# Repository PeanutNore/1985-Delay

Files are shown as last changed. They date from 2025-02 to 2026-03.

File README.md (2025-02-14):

# 1985-Delay
A Digital Delay pedal for guitar built around the AVR128DA28 MCU
    
This program is distributed in the hope that it will be useful,
but WITHOUT ANY WARRANTY; without even the implied warranty of
MERCHANTABILITY or FITNESS FOR A PARTICULAR PURPOSE.

 * Copyright 2025 Samuel Brown. All Rights Reservered.
 * 
 * Licensed under Creative Commons CC-BY-NC-SA 4.0
 * https://creativecommons.org/licenses/by-nc-sa/4.0/
 * 
 * You are free to share and adapt this software for non-
 * commercial purposes provided that you give appropriate 
 * credit and attribution, and distribute your contributions 
 * under the same CC-BY-NC-SA license.
 * 
 * For commercial licensing contact sam.brown.rit08@gmail.com

The maximum delay time available depends on the sample rate used and the bit depth of delay samples.
Main branch (1985_Delay) provides 1.4 seconds of delay at 10kHz and 8 bits and is tested and working with minor issues.
Highres branch (1985_Delay_Highres) provides 700ms of delay at 10kHz and 12 bits and is untested.

Adjust the sample rate as desired to balance available delay time and audio quality.

To use this software you will need:
* Arduino IDE version 1.8.19 or greater
* DxCore library for AVR128DA28 support (https://github.com/SpenceKonde/DxCore)
* Any USB to UPDI programmer. I recommend the Adafruit UPDI Friend because it is easy to use and under $20
* An AVR128DA28 MCU and appropriate supporting circuitry. Refer to the KiCad schematic and board files included in this repository.

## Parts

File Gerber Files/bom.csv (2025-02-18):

Designator | Footprint | Quantity | Value | LCSC Part #
C11, C16 | 603 | 2 | 1n2
C12 | 603 | 1 | 100n
C13 | 603 | 1 | 1n
C14, C6, C9 | 603 | 3 | 10n
C3, C5 | 1210 | 2 | 1u
R10, R11, R12, R13, R14, R15, R16, R17, R19, R7 | 805 | 10 | 22k
R18, R6 | 805 | 2 | 9k1
R20, R21, R5, R8, R9 | 805 | 5 | 1M
R4 | 805 | 1 | 1k
U1 | SOT-89-3 | 1 | L78L05
U2, U3 | SOT-89-3 | 2 | L78L33

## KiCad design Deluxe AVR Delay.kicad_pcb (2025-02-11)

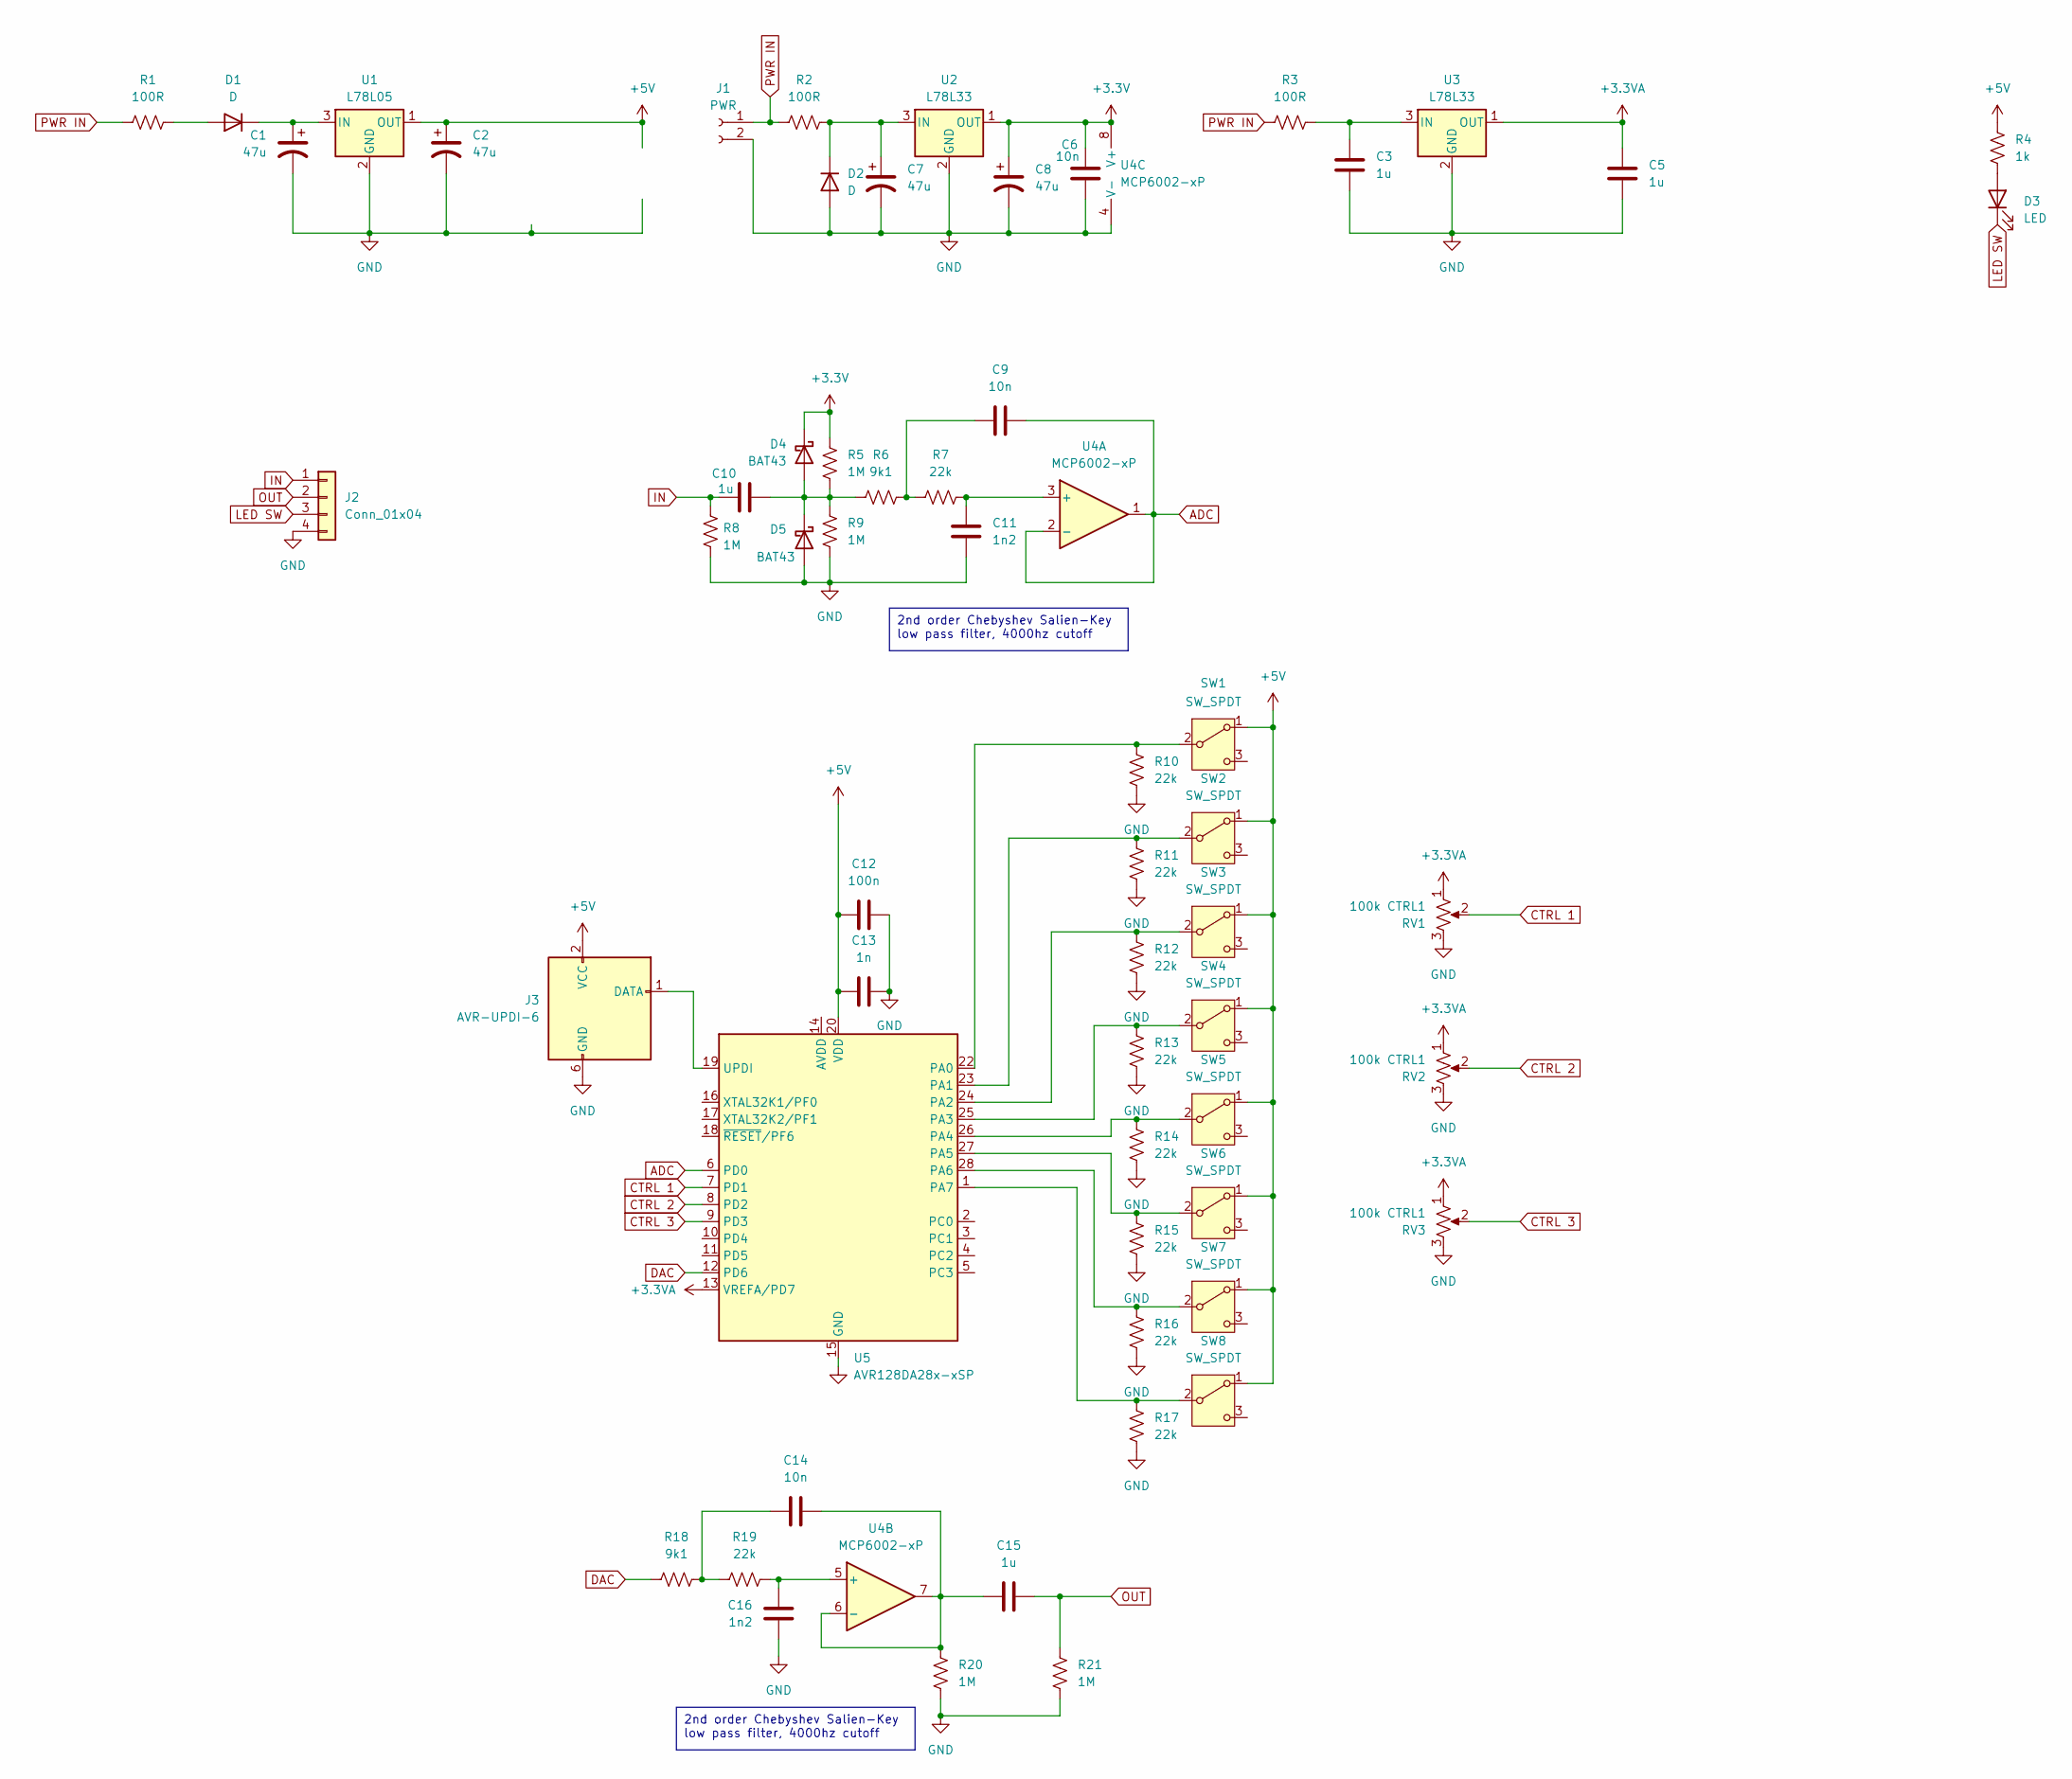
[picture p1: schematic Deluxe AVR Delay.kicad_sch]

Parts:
C1, C2, C7, C8: 47u; CP_Radial_D5.0mm_P2.50mm
C3, C5: 1u; C_1210_3225Metric
C6, C9, C14: 10n; C_0603_1608Metric
C10, C15: 1u; C_Rect_L7.0mm_W6.5mm_P5.00mm
C11, C16: 1n2; C_0603_1608Metric
C12: 100n; C_0603_1608Metric
C13: 1n; C_0603_1608Metric
D1, D2: D; D_DO-35_SOD27_P7.62mm_Horizontal
D3: LED; LED_D3.0mm
D4, D5: BAT43; D_DO-35_SOD27_P7.62mm_Horizontal
J1: PWR; PinHeader_1x02_P2.54mm_Vertical
J2: Conn_01x04; PinHeader_1x04_P2.54mm_Vertical
J3: AVR-UPDI-6; PinHeader_2x03_P2.54mm_Vertical
R1, R2, R3: 100R; R_Axial_DIN0207_L6.3mm_D2.5mm_P7.62mm_Horizontal
R4: 1k; R_0805_2012Metric
R5, R8, R9, R20, R21: 1M; R_0805_2012Metric
R6, R18: 9k1; R_0805_2012Metric
R7, R10, R11, R12, R13, R14, R15, R16, R17, R19: 22k; R_0805_2012Metric
RV1, RV2, RV3: 100k CTRL1; RV16AF-41
SW1, SW2, SW3, SW4, SW5, SW6, SW7, SW8: SW_SPDT; 2MS1T1B3M2QES
U1: L78L05; SOT-89-3
U2, U3: L78L33; SOT-89-3
U4: MCP6002-xP; DIP-8_W7.62mm_Socket
U5: AVR128DA28x-xSP; DIP-28_W7.62mm

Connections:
+3.3V: C6.1, C8.1, D4.1 (K), R5.1, U2.1 (OUT), U4.8 (V+)
+3.3VA: C5.2, RV1.1, RV2.1, RV3.1, U3.1 (OUT), U5.13 (VREFA/PD7)
+5V: C2.1, C12.1, C13.1, J3.2 (VCC), R4.1, SW1.1 (A), SW2.1 (A), SW3.1 (A), SW4.1 (A), SW5.1 (A), SW6.1 (A), SW7.1 (A), SW8.1 (A), U1.1 (OUT), U5.20 (VDD)
ADC: C9.2, U4.1, U4.2 (-), U5.6 (PD0)
CTRL 1: RV1.2, U5.7 (PD1)
CTRL 2: RV2.2, U5.8 (PD2)
CTRL 3: RV3.2, U5.9 (PD3)
DAC: R18.1, U5.12 (PD6)
GND: C1.2, C2.2, C3.1, C5.1, C6.2, C7.2, C8.2, C11.2, C12.2, C13.2, C16.2, D2.2 (A), D5.2 (A), J1.2, J2.4, J3.6 (GND), R8.2, R9.2, R10.1, R11.1, R12.1, R13.1, R14.1, R15.1, R16.1, R17.1, R20.2, R21.2, RV1.3, RV2.3, RV3.3, U1.2 (GND), U2.2 (GND), U3.2 (GND), U4.4 (V-), U5.15 (GND), U5.21 (GND)
IN: C10.1, J2.1, R8.1
LED SW: D3.1 (K), J2.3
unnamed: C9.1, R6.2, R7.1
unnamed: C14.1, R18.2, R19.1
unnamed: D1.2 (A), R1.2
unnamed: C1.1, D1.1 (K), U1.3 (IN)
unnamed: C7.1, D2.1 (K), R2.2, U2.3 (IN)
unnamed: D3.2 (A), R4.2
unnamed: C10.2, D4.2 (A), D5.1 (K), R5.2, R6.1, R9.1
unnamed: J3.1 (DATA), U5.19 (UPDI)
unnamed: R10.2, SW1.2 (B), U5.22 (PA0)
unnamed: R11.2, SW2.2 (B), U5.23 (PA1)
unnamed: R12.2, SW3.2 (B), U5.24 (PA2)
unnamed: R13.2, SW4.2 (B), U5.25 (PA3)
unnamed: R14.2, SW5.2 (B), U5.26 (PA4)
unnamed: R15.2, SW6.2 (B), U5.27 (PA5)
unnamed: R16.2, SW7.2 (B), U5.28 (PA6)
unnamed: R17.2, SW8.2 (B), U5.1 (PA7)
unnamed: C3.2, R3.2, U3.3 (IN)
unnamed: C11.1, R7.2, U4.3 (+)
unnamed: C16.1, R19.2, U4.5 (+)
unnamed: C14.2, C15.1, R20.1, U4.6 (-), U4.7
OUT: C15.2, J2.2, R21.1
PWR IN: J1.1, R1.1, R2.1, R3.1

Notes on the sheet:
2nd order Chebyshev Salien-Key low pass filter, 4000hz cutoff

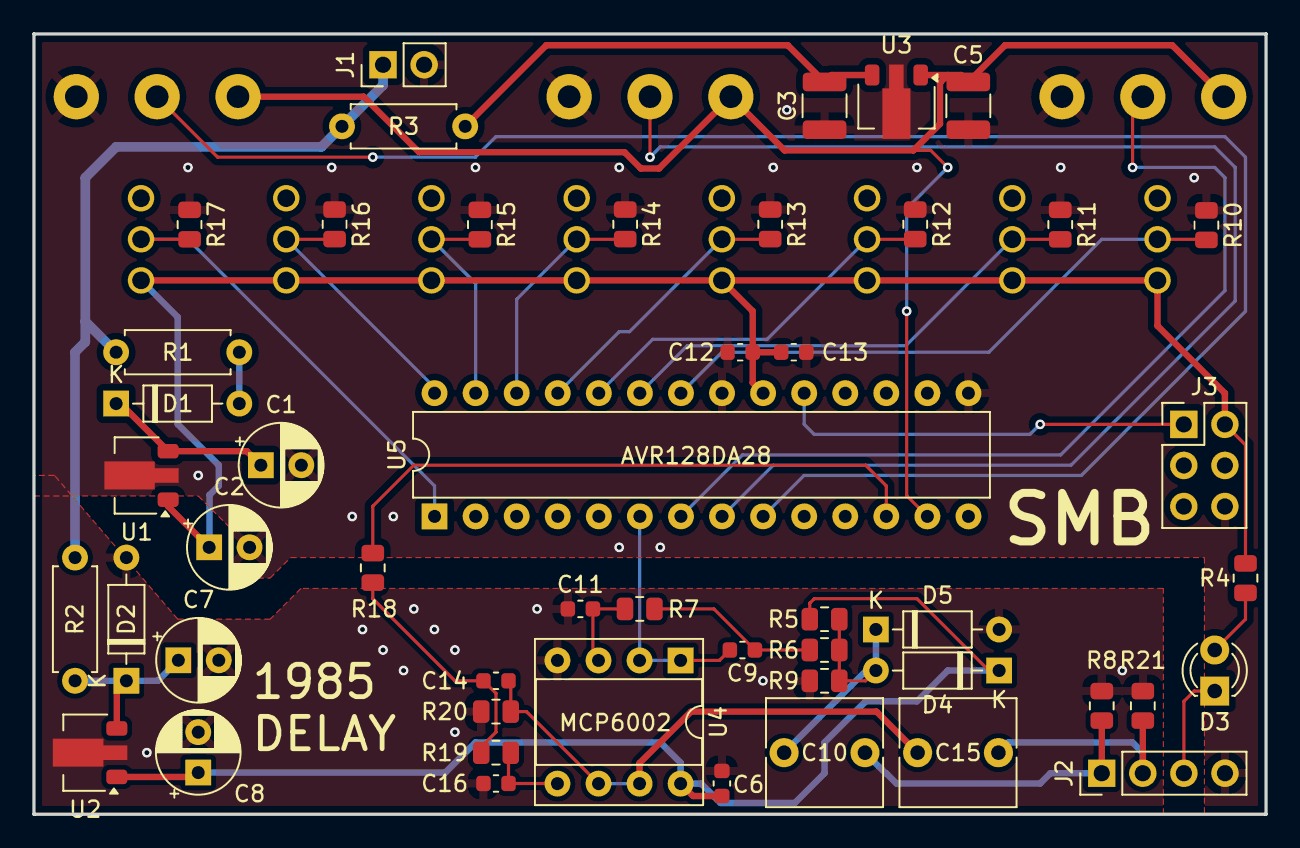
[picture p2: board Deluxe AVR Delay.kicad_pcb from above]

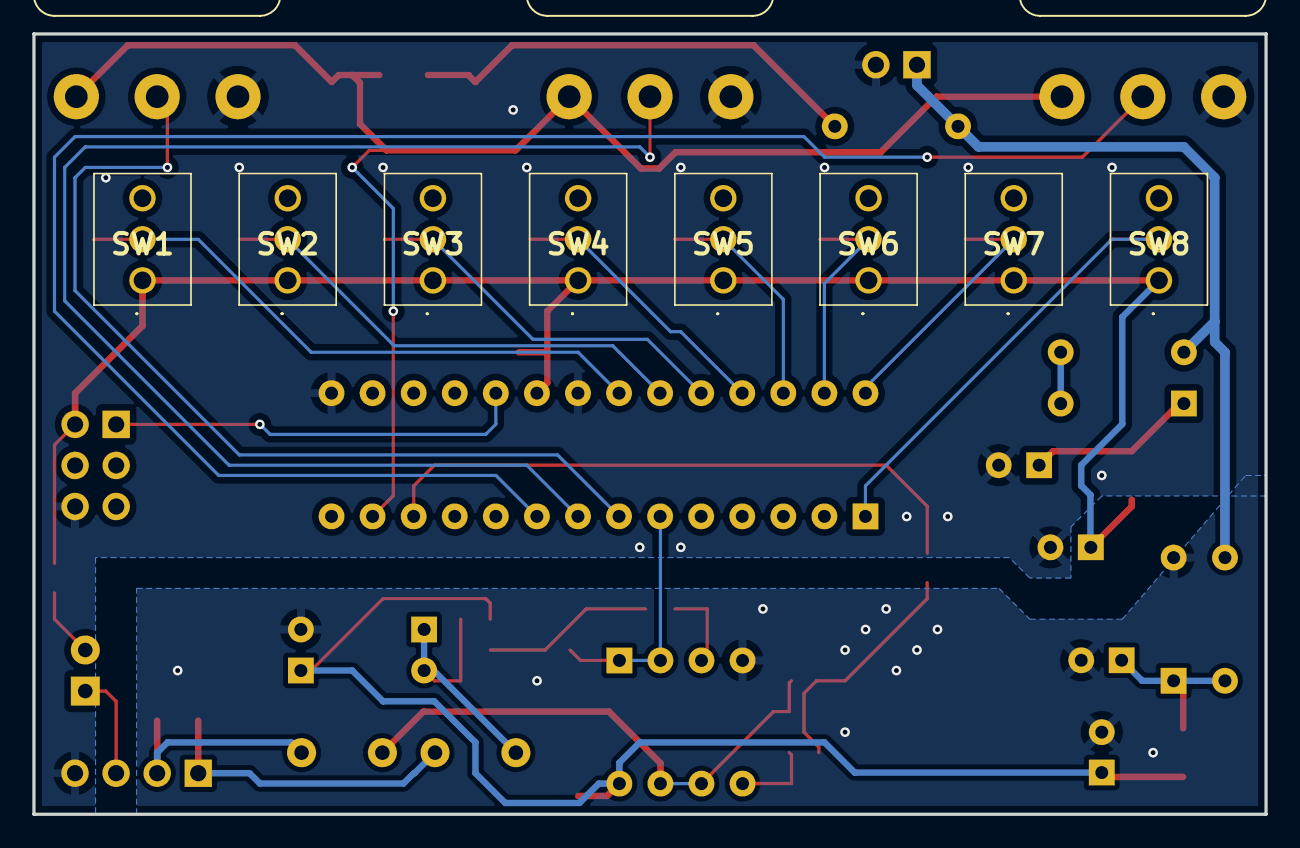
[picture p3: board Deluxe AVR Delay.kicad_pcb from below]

Board: 2 copper layers, 76.2 x 48.3 mm, 60 parts (11 on the bottom side), 33 nets.

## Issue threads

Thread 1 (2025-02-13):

Repeats louder than unity gain

PeanutNore, 2025-02-13:
at the center settings of the mix control, the repeats sound louder than unity gain as compared to the dry signal. this may be distortion caused by storing only the 8 most significant bits of the delayed sample.

possible fixes:

- store the full 10 bits of the delayed sample (cost: halves delay time, but there's a lot of delay time)
- cap delayed sample amplitude to 512 (9 bits)

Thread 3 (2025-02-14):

Temporal isolation of analogRead()s

PeanutNore, 2025-02-14:
To reduce jitter, isolate the analogRead()s from each other. Each one should be done immediately before that variable is first used within the ISR.

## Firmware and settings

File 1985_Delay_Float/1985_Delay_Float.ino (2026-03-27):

//Pin Assignments
uint8_t OutputPin = PIN_PD6;
uint8_t InputPin = PIN_PD0;
uint8_t TimePin = PIN_PD2;
uint8_t MixPin = PIN_PD1;
uint8_t FbkPin = PIN_PD3;
//Audio Samples
int16_t inSample;
int16_t delaySample;
float drySample;
float wetSample;
float storeSample;
float outSample;
int16_t intSample;
uint16_t dacSample;
int16_t delayArray[4096];

//Step Counters
uint16_t sampleStep = 0;
uint16_t delayStep = 0;

//Controls
uint16_t mixRaw = 0;
float mixFactor = 0.0;
uint16_t fbkRaw = 0;
float fbkFactor = 0.0;
uint16_t delaySet = 0;
uint16_t delayTimeNew = 0;
uint16_t delayTime = 0;

ISR(TCA0_OVF_vect) {
  //experiment here - clearing the interrupt flag first
  TCA0.SINGLE.INTFLAGS = TCA_SINGLE_OVF_bm;                 //clear the interrupt flags
  //get the input as a signed int
  inSample = analogRead(InputPin) - 2048;
  //get the signed int delayed sample
  delaySample = delayArray[delayStep];
  
  //convert the dry sample to a float between 1 and -1
  drySample = inSample / 2048.0;
  //convert the wet sample to a float between 1 and -1
  wetSample = delaySample / 2048.0;
  //prepare the sample to store in the array by starting with the feedback
  storeSample = wetSample;
  //attenuate the feedback
  storeSample *= fbkFactor;
  //add the dry sample
  storeSample += drySample;
  //convert to signed int
  delaySample = storeSample * 2048;
  //store the signed int sample in the delay
  delayArray[sampleStep] = delaySample;
  //attenuate the wet sample
  wetSample *= mixFactor;
  //combine the dry and wet samples together
  outSample = drySample + wetSample;
  //convert back to a signed int
  intSample = outSample * 2048;
  //constrain to the limits of the dac and make it unsigned
  if(intSample > 2047){intSample = 2047;}
  else if (intSample < -2048){intSample = -2048;}
  dacSample = intSample + 2048;
  dacSample = dacSample >> 2;
  //output to dac
  DAC0.DATAL = dacSample << 6;
  DAC0.DATAH = dacSample >> 2;
  //read the controls
  mixRaw = 4095 - (analogRead(MixPin) & 0b0000111111111100);
  mixFactor = mixRaw / 4095.0;
  fbkRaw = 4095 - (analogRead(FbkPin) & 0b0000111111111100);
  fbkFactor = fbkRaw / 4095.0;
  delayTimeNew = 4095 - (analogRead(TimePin) & 0b0000111111111100);
  if(delayTime < delayTimeNew){delayTime++;}
  else if (delayTime > delayTimeNew){delayTime--;}
  //increment the steps
  sampleStep++;
  sampleStep &= 0x0FFF;
  delayStep = sampleStep - delayTime;
  delayStep &= 0x0FFF;
  
}

void setup() {
  // put your setup code here, to run once:
for (int i = 0; i < 4096; i++){
  delayArray[i] = 0.0;
}
pinMode(OutputPin, OUTPUT);
pinMode(InputPin, INPUT);
pinMode(TimePin, INPUT);
pinMode(MixPin, INPUT);
pinMode(FbkPin, INPUT);
analogReference(EXTERNAL);
DACReference(EXTERNAL); //found to be missing when testing on final hardware- not an issue on the breadboard running everything at 5V
analogReadResolution(12);
analogSampleDuration(0);

mixRaw = analogRead(MixPin);
delayTime = 4095 - (analogRead(TimePin) & 0b0000111111111100);
mixFactor = mixRaw / 4095.0;

DAC0.DATAL = 0b00000000;
DAC0.DATAH = 0b10000000;
DAC0.CTRLA = 0b11000001;
takeOverTCA0();
TCA0.SINGLE.INTFLAGS = TCA_SINGLE_OVF_bm;
TCA0.SINGLE.INTCTRL  = 0b00000001; // overflow interrupt every PER cycles
TCA0.SINGLE.CTRLA    = TCA_SINGLE_CLKSEL_DIV1_gc; // Clock prescaler / 1 (24 MHz)    
TCA0.SINGLE.PER      = 1000;        // 300 * 8 = 2400 clocks, for a 10kHz sample rate, 200 * 8 = 1600 clocks 15kHz sample rate, 150 * 8 = 1200 clocks 20kHz sample rate, 125 * 8 = 1000 clocks 24kHz sample rate
TCA0.SINGLE.CTRLA   |= 1;          // Enables the timer                 
}

void loop() {
  // put your main code here, to run repeatedly:

}

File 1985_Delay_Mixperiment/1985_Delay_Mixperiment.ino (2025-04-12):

/* 1985 Delay
 * Digital Delay Pedal for Guitar
 * High resolution version with half delay time - reads and stores full 12 bit samples in delay array
 * Version 0.2 - tested and working on breadboard
 * 
 *
 * 
 * For AVR512DA28 microcontrollers using DxCore library
 * 
 * Copyright 2025 Samuel Brown. All Rights Reservered.
 * 
 * Licensed under Creative Commons CC-BY-NC-SA 4.0
 * https://creativecommons.org/licenses/by-nc-sa/4.0/
 * 
 * You are free to share and adapt this software for non-
 * commercial purposes provided that you give appropriate 
 * credit and attribution, and distribute your contributions 
 * under the same CC-BY-NC-SA license.
 * 
 * For commercial licensing contact sam.brown.rit08@gmail.com
 */

//Pin Assignments
uint8_t OutputPin = PIN_PD6;
uint8_t InputPin = PIN_PD0;
uint8_t TimePin = PIN_PD2;
uint8_t MixPin = PIN_PD1;
uint8_t FbkPin = PIN_PD3;
//Audio Samples
uint16_t sampleIn;
uint16_t sampleDelay;
uint16_t sampleFbk;
uint16_t sampleOut;
uint8_t sampleOutHigh;
uint8_t sampleOutLow;
int16_t mathIn;
int16_t mathDelay;
int16_t mathFbk;
int16_t mathOut;
uint16_t delayArray[8000];
//Step Counters
uint16_t sampleStep = 0;
uint16_t delayStep = 0;
//Controls
uint16_t delayTime = 0;
uint16_t mix = 8;
uint16_t fbk = 8;
//Lookup Tables
uint16_t mixOffsets[17] = {0, 1920, 1792, 1664, 1536, 1408, 1280, 1152, 1024, 896, 768, 640, 512, 384, 256, 128, 0};

ISR(TCA0_OVF_vect) {
  //experiment here - clearing the interrupt flag first
  TCA0.SINGLE.INTFLAGS = TCA_SINGLE_OVF_bm;                 //clear the interrupt flags
  //this concludes the experiment. don't forget about the commented line below.
  //read the audio input
  sampleIn = analogRead(InputPin);                          

  //read the delay time
  delayTime = analogRead(TimePin) >> 4;
  ADC0.MUXPOS = ((InputPin & 0x7F) << ADC_MUXPOS_gp);
  delayTime *= 32;
  if (delayTime > 7998){delayTime = 7998;}

  //set the delay step
  delayStep = sampleStep + 1;
  delayStep += delayTime;
  if (delayStep > 7999) {delayStep -= 8000;}

  //get the delayed sample from the array
  sampleDelay = delayArray[delayStep];
  sampleFbk = sampleDelay;
  
  //compute the feedback amount and store the new sample with feedback in the delay array
  fbk = analogRead(FbkPin) >> 8;
  fbk ^= 0x000F;
  if (fbk > 0 ){fbk++;}
  sampleFbk *= fbk;
  sampleFbk = sampleFbk >> 4;
  sampleFbk += mixOffsets[fbk];
  mathFbk = sampleFbk - 2048;
  sampleIn += analogRead(InputPin);   //read the input a second time...
  sampleIn = sampleIn >> 1;           //and average them to reduce quantization noise
  mathIn = sampleIn - 2048;
  mathFbk += mathIn;
  if (mathFbk > 2047){mathFbk = 2047;}
  if (mathFbk < -2048){mathFbk = -2048;}
  delayArray[sampleStep] = mathFbk + 2048;
  
  //compute the mix of sample in and delay sample and prepare sample out
  mix = analogRead(MixPin) >> 8;
  mix ^= 0x000F;
  mix++;
  sampleDelay *= mix;
  sampleDelay = sampleDelay >> 4;
  sampleDelay += mixOffsets[mix];
  mathDelay = sampleDelay - 2048;  
  mathOut = mathIn + mathDelay;
  if (mathOut > 2047){mathOut = 2047;}
  if (mathOut < -2048){mathOut = -2048;}
  sampleOut = mathOut + 2048;
  sampleOut = sampleOut >> 2;
  sampleOutLow = sampleOut << 6;               //variable for to sends the 2 lowest bits of the audio sample to the DAC
  sampleOutHigh = sampleOut >> 2;              //variable for to sends the 8 highest bits of the sample to the DAC 
  sampleStep++;
  if (sampleStep > 7999){sampleStep = 0;}
  DAC0.DATAL = sampleOutLow;                  //make sending of low bits
  DAC0.DATAH = sampleOutHigh;                 //make sending of high bits and be triggering DAC output
  //TCA0.SINGLE.INTFLAGS = TCA_SINGLE_OVF_bm;                 //clear the interrupt flags (commented out for experiment)
  ADC0.MUXPOS = ((InputPin & 0x7F) << ADC_MUXPOS_gp);
}

void setup() {
for (int i = 0; i < 8000; i++){
  delayArray[i] = 512;
}
pinMode(OutputPin, OUTPUT);
pinMode(InputPin, INPUT);
pinMode(TimePin, INPUT);
pinMode(MixPin, INPUT);
pinMode(FbkPin, INPUT);
analogReference(EXTERNAL);
DACReference(EXTERNAL); //found to be missing when testing on final hardware- not an issue on the breadboard running everything at 5V
analogReadResolution(12);
analogSampleDuration(0);
delayTime = analogRead(TimePin) >> 2;
delayTime *= 8;
if (delayTime > 7999){delayTime = 7999;}
DAC0.DATAL = 0b00000000;
DAC0.DATAH = 0b10000000;
DAC0.CTRLA = 0b11000001;
takeOverTCA0();
TCA0.SINGLE.INTFLAGS = TCA_SINGLE_OVF_bm;
TCA0.SINGLE.INTCTRL  = 0b00000001; // overflow interrupt every PER cycles
TCA0.SINGLE.CTRLA    = TCA_SINGLE_CLKSEL_DIV1_gc; // Clock prescaler / 1 (24 MHz)    
TCA0.SINGLE.PER      = 1000;        // 300 * 8 = 2400 clocks, for a 10kHz sample rate, 200 * 8 = 1600 clocks 15kHz sample rate, 150 * 8 = 1200 clocks 20kHz sample rate, 125 * 8 = 1000 clocks 24kHz sample rate
TCA0.SINGLE.CTRLA   |= 1;          // Enables the timer                 

}

void loop() {
  // put your main code here, to run repeatedly:

}

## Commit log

2025-02-13 Add files via upload
    Fixed missing step counter increment causing only dry signal to be heard
    [1985_Delay.ino]
2025-02-13 Add files via upload
    reversed order of mix lookups to match the sweep of the potentiometer
    [1985_Delay.ino]
2025-02-14 New High Resolution Mode
    This (as yet untested) mode changes the delay array to uint16_t and stores the full resolution sample in the delay array, at the cost of halving the amount of delay time available (approximately 700m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
2025-02-15 Increased sample rate. Tested, working.
2025-02-18 Multiple enhancements & possible fix for Issue #2
    - Experimental changes to interrupt timer
    - Tested on final hardware & working
    - Added line to discard very small feedback samples to possibly fix issue #2
    [1985_Delay_Highres.ino]
2025-02-18 Added Gerber files for ordering PCBs
    I have assembled and validated one of these boards that I had produced and assembled with SMD components by JLCPCB.
    WARNING!
    WHEN ORDERING ASSEMBLED BOARDS, CONFIRM THE VOLTAGE REGULATORS ARE ORIENTED CORRECTLY BEFORE PLACING AN ORDER!
    DAMAGE MAY RESULT IF THE VOLTAGE REGULATORS ARE INSTALLED BACKWARDS.
    [bom.csv, positions.csv]
2025-02-18 Updated DACReference() to EXTERNAL
    This was missing from previous versions - on the breadboard it didn't matter since everything was at 5V anyway but on final hardware the analog side runs at 3.3v
    [1985_Delay_Highres.ino]
2025-04-12 Experimenting with a simplified mixing method
    This is a standard delay that attempts to simplify the way that feedback and dry signal is mixed and hopefully improve audio quality. Also reduces the resolution of the delay control to 8 bit to maybe help with noise. A capacitor might be needed on the delay time pin to reduce the functional impedance.
    [1985_Delay_Mixperiment.ino]
2026-03-27 Added new Floating Point version
    1985 Delay Float offers an improved noise floor and superior feedback and mix controls at the expense of sample rate.
    I think it sounds really cool.
    [1985_Delay_Float.ino]
2026-03-27 Change delaySample scaling factor from 4095 to 2048
    This fixes a typo
    [1985_Delay_Float.ino]
